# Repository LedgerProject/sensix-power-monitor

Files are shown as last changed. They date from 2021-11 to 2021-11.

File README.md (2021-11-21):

## SPD Enclosure based PowerMonitor - 2 DIN Modules - Single/Three Phase

## Table of contents

* [Built with](#built-with)
* [Software used](#dependencies)
* [Directory structure](#directory-structure)
* [Flash instructions](#flash-instructions)
* [Running tests](#running-tests)
* [Hardware Design](#hardware-design)

## Built with 

* [ESP-IDF](https://www.espressif.com/en/products/sdks/esp-idf)

## Software used 

* [ESP-IDF Toolchain](https://www.espressif.com/en/products/sdks/esp-idf)
* [CMake](https://cmake.org/download/)
* [Arduino ADE9153a](https://github.com/analogdevicesinc/arduino/tree/master/Arduino%20Uno%20R3/libraries/ADE9153A)
* [minfft](https://github.com/aimukhin/minfft)
* [fmtlib](https://github.com/fmtlib/fmt)
* [Microsoft GSL](https://github.com/microsoft/GSL)

## Directory structure 

* `3rdparty`: Third party code and dependencies
* `cmake`: Additional CMake scripts used to configure and build the project
* `data`: Resources embedded in the final binary
* `hardware_design`: Hardware design files
* `main`: ESP IDF component
* `src`: Source code
* `src/include`: Header files
* `test`: Unit tests (meant to be run on PC)

## Flash instructions 

After setting up the ESP IDF build environment and making sure the tools are available in your PATH, run:

```
idf.py build # Build the source code
idf.py -p <port> flash
idf.py -p <port> monitor
```

## Running tests 

Make sure you have CMake and CTest available in your PATH and a C and C++ compiler available.

Run:

```
mkdir build && cd build
cmake .. && cmake --build .
ctest
```

## Hardware Design 

Design files for PowerMonitor hardware for development:

* SPD_PowerMonitor-AFE - board containing the analog frontend and isolation barrier
* SPD_PowerMonitor-Controller - board containing the ESP32 MCU with RS485 and USB for software debugging

Characteristics:

* Designed to fit into a 2 DIN Module SPD base enclosure
* Instead of Ethernet and 24V AC power the controller has a USB transciever chip to ease development
* Powered by USB 5V DC
* Breakout headers for internal SPI bus in order to experiment with external RAM
* Breakout headers for I2C bus to add ST NFC module for configuration loading
* Shunt mounted directly on the SPD spade plugs

**Notes**

From software side this is the final design, any changes to hardware should be transparent to software. On hardware
side, because of chip shortages and especially the low availability of the isolated power supply for the AFE, this
design will have to be modified to use other ICs that are available. Analog FE will not change.

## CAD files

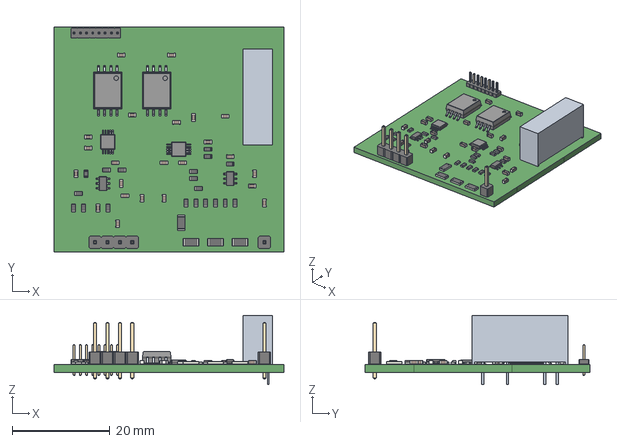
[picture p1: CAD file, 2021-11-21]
hardware_design/PowerMonitor-AFE/PowerMonitor-AFE/PowerMonitor-AFE.step
47.0 x 46.0 x 14.2 mm

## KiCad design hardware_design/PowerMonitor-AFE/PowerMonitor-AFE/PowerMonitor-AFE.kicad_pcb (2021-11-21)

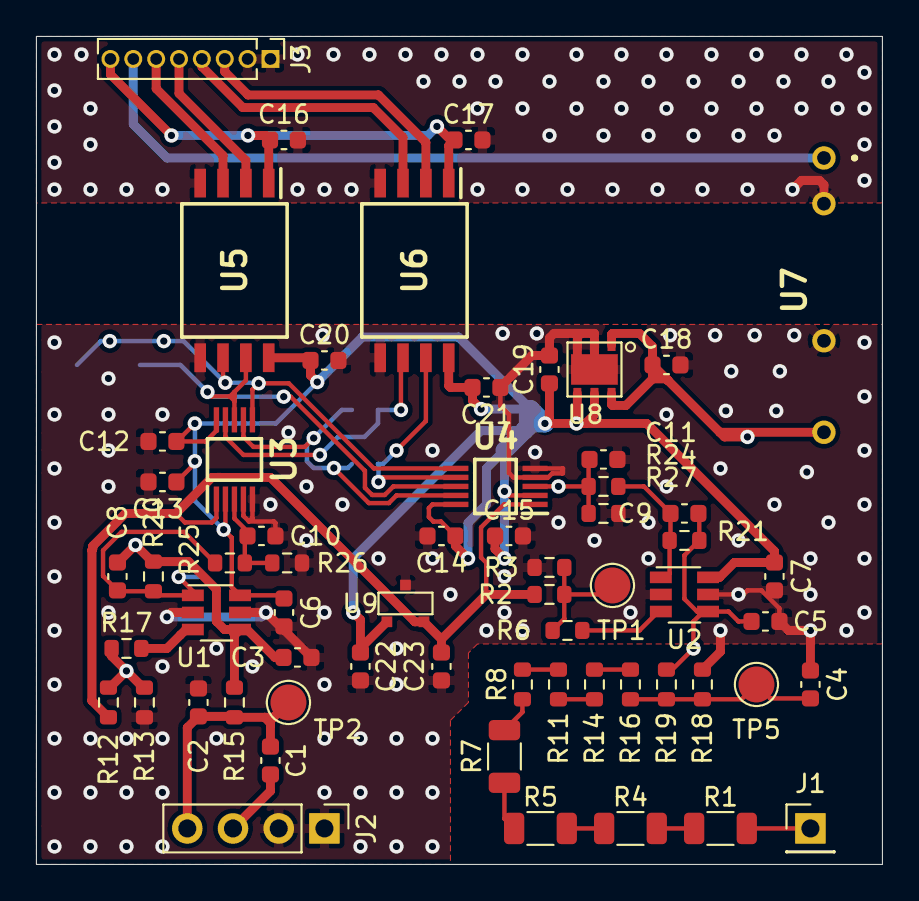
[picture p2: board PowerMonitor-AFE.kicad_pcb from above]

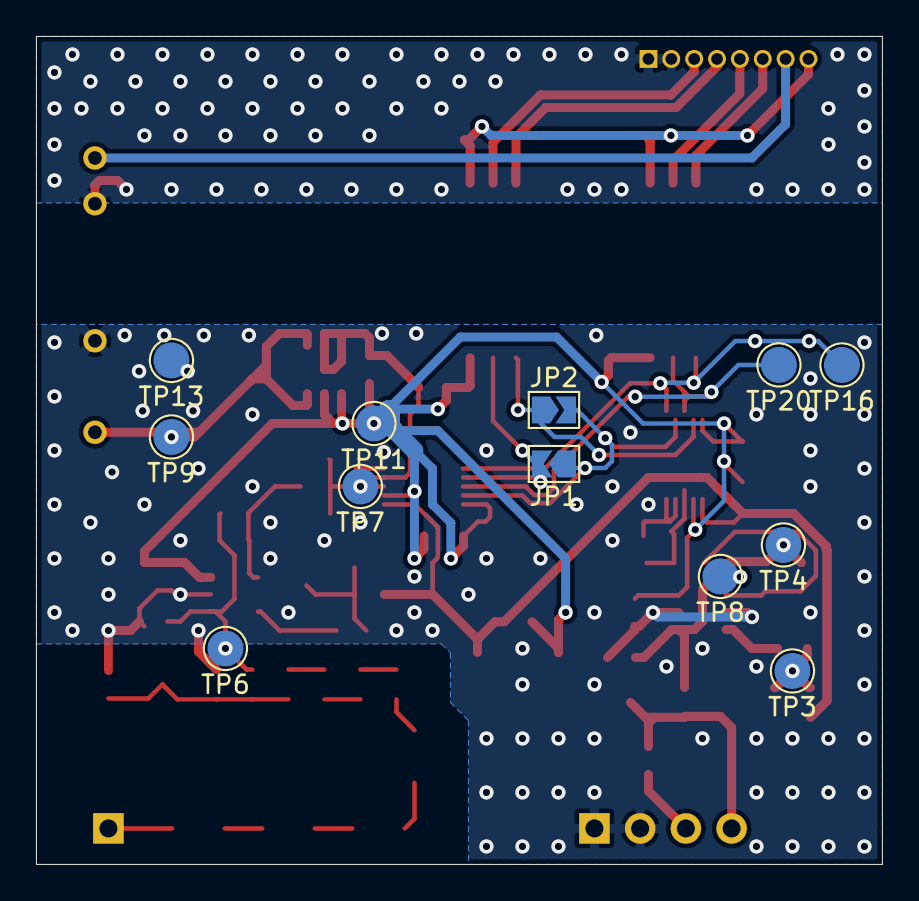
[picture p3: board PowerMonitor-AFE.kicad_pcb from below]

Board: 2 copper layers, 47.0 x 46.0 mm, 73 parts (12 on the bottom side), 37 nets.

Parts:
C1, C3, C5, C8, C9, C10, C11: DNP; C_0603_1608Metric
C2, C4: 1n; C_0603_1608Metric
C6, C7, C12, C13, C14, C15, C16, C17, C20, C21, C22: 0.1u; C_0603_1608Metric
C18, C19, C23: 1u; C_0603_1608Metric
J1: Conn_01x01; PinHeader_1x01_P2.54mm_Vertical
J2: Conn_01x04; PinHeader_1x04_P2.54mm_Vertical
J3: Conn_01x08; PinHeader_1x08_P1.27mm_Vertical
JP1, JP2: SolderJumper_2_Open; SolderJumper-2_P1.3mm_Open_TrianglePad1.0x1.5mm
R1, R4, R5, R7: 249k; R_1206_3216Metric
R2, R8, R11, R12, R14, R16, R24, R25, R26, R27: 1k; R_0603_1608Metric
R3, R13: 100; R_0603_1608Metric
R6, R17: 0R; R_0603_1608Metric
R15: 100K; R_0603_1608Metric
R18: 330; R_0603_1608Metric
R19: 100k; R_0603_1608Metric
R20, R21: 1M; R_0603_1608Metric
TP1, TP2, TP3, TP4, TP5, TP6, TP7, TP8, TP9, TP11, TP13, TP16, TP20: TestPoint; TestPoint_Pad_D2.0mm
U1, U2: ADA4098-1; TSOT-23-6
U3, U4: ADS8866; SOP50P490X110-10N
U5: MAX22245; SOIC127P1031X265-8N
U6: MAX22246; SOIC127P1031X265-8N
U7: TEA1-0505HI; TEA10505HI
U8: NCP691MN33T2G; DFN6 3x3 0.95
U9: ADR380ARTZ-REEL7; SOT-23

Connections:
+3.3VP: C6.2, C7.2, C12.2, C13.1, C14.2, C15.1, C19.1, C20.1, C21.1, C22.1, TP11.1, U1.6, U2.6, U3.2, U3.10, U4.2, U4.10, U5.8, U6.8, U8.4, U8.5, U9.1
+3V3: C16.1, C17.1, J3.8, U5.1, U6.1
+5V: J3.7, U7.1
+5VP: C18.1, TP9.1, U7.7, U8.1, U8.6
CONVST: TP16.1, U3.6, U4.6, U5.6
CONV_START: J3.6, U5.3
DIN_EXT: JP2.1, U3.9, U6.6
DOUT_A: JP1.1, JP2.2, U3.7, U4.9
DOUT_EXT: JP1.2, U4.7, U6.7
GND1: C16.2, C17.2, J3.1, J3.2, U5.4, U6.4, U7.2
GND2: C2.1, C3.1, C4.1, C5.1, C6.1, C7.1, C10.1, C11.1, C12.1, C13.2, C14.1, C15.2, C18.2, C19.2, C20.2, C21.2, C22.2, C23.2, J2.1, J2.2, R3.1, R13.1, R18.2, R26.2, R27.2, TP13.1, U1.2, U1.5, U2.2, U2.5, U3.4, U3.5, U4.4, U4.5, U5.5, U6.5, U7.5, U8.2, U8.3, U8.EP, U9.3
unnamed: C1.1, C2.2, J2.4, R15.1, TP2.1
unnamed: C1.2, J2.3
unnamed: C3.2, C8.2, R15.2, R20.2, TP4.1, U1.4
unnamed: C4.2, R16.2, R18.1, R19.1, TP5.1
unnamed: C5.2, C9.2, R19.2, R21.2, TP6.1, U2.4
unnamed: C8.1, R20.1, R25.1, TP8.1, U1.1
unnamed: C9.1, R21.1, R24.1, U2.1
unnamed: C10.2, R25.2, R26.1, U3.3
unnamed: C11.2, R24.2, R27.1, TP7.1, U4.3
unnamed: J1.1, R1.1
unnamed: R1.2, R4.1
unnamed: R2.2, R3.2, R6.1, TP1.1
unnamed: R4.2, R5.1
unnamed: R5.2, R7.1
unnamed: R6.2, U2.3
unnamed: R7.2, R8.1
unnamed: R8.2, R11.1
unnamed: R11.2, R14.1
unnamed: R12.2, R13.2, R17.1, TP3.1
unnamed: R14.2, R16.1
unnamed: R17.2, U1.3
SCLK: TP20.1, U3.8, U4.8, U5.7
SPI_0_CLK: J3.5, U5.2
SPI_0_MISO: J3.3, U6.2
SPI_0_MOSI: J3.4, U6.3
VREF: C23.1, R2.1, R12.1, U3.1, U4.1, U9.2

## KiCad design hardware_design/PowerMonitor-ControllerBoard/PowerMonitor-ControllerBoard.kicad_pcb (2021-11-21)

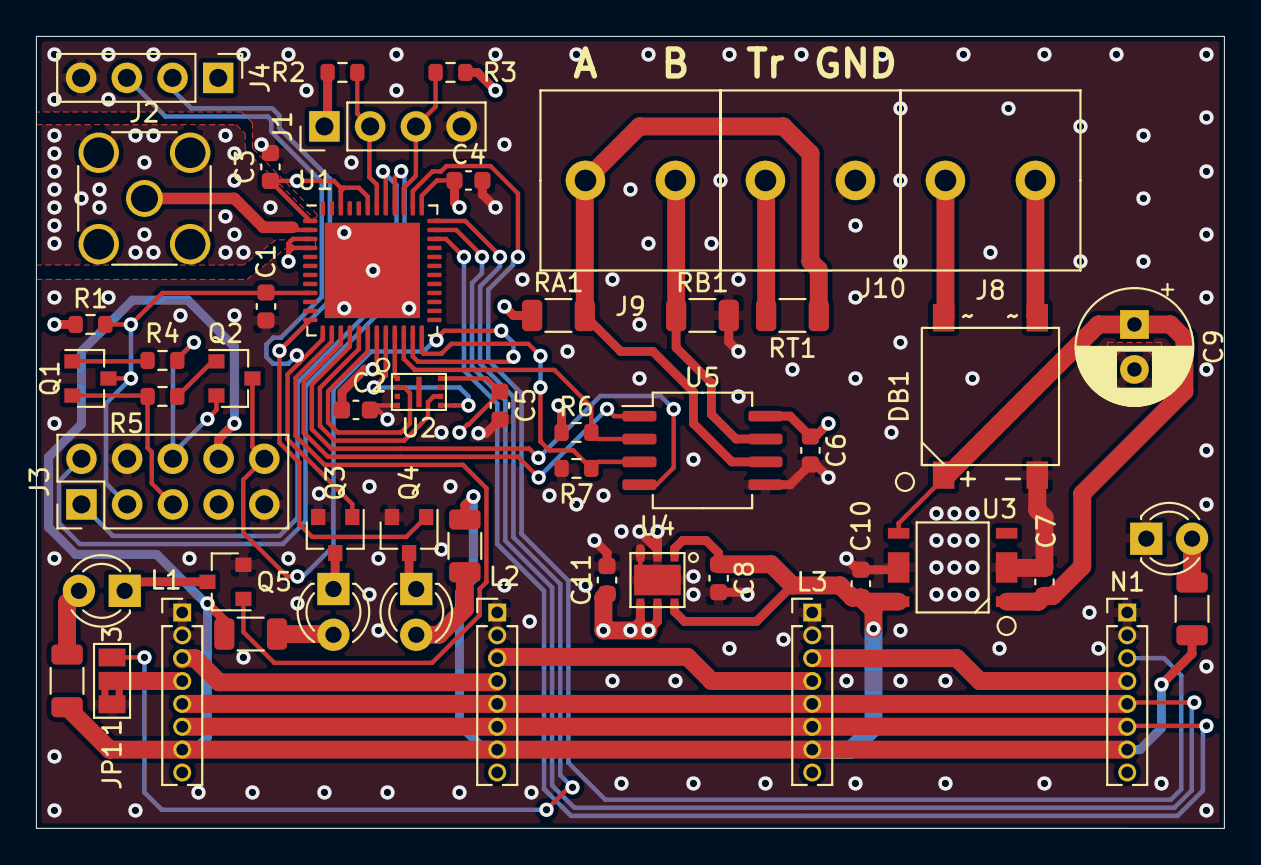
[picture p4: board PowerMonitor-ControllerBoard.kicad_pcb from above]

Board: 4 copper layers, 66.0 x 44.0 mm, 52 parts (0 on the bottom side), 46 nets.

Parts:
C1, C2, C3, C4, C5, C6, C7, C10: 0.1u; C_0603_1608Metric
C8, C11: 1u; C_0603_1608Metric
C9: 4700u; CP_Radial_D6.3mm_P2.50mm
DB1: DF01S-T
J1: CON_I2C; PinHeader_1x04_P2.54mm_Vertical
J2: Conn_Coaxial; SMA_Wurth_60312002114503_Vertical
J3: Conn_02x05_Counter_Clockwise; PinHeader_2x05_P2.54mm_Vertical
J4: Conn_01x04; PinHeader_1x04_P2.54mm_Vertical
J8, J9, J10: Conn_01x02; 1792863
JP1: DATA_OUT_SEL; SolderJumper-3_P1.3mm_Bridged2Bar12_Pad1.0x1.5mm_NumberLabe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
L1, L2, L3: Conn_01x08; PinHeader_1x08_P1.27mm_Vertical
LED_ACT1: LED; LED_D3.0mm
LED_ALERT_1, LED_ALERT_2: LED; LED_D3.0mm
LED_PWR1: LED; LED_D3.0mm
N1: Conn_01x08; PinHeader_1x08_P1.27mm_Vertical
Q1, Q2, Q3, Q4, Q5: Q_NPN_BEC; SOT-23
R1, R6, R7: 10k; R_0603_1608Metric
R2, R3: 2k2; R_0603_1608Metric
R4, R5: 1k; R_0603_1608Metric
RA1: 1k; R_1206_3216Metric
RB1: 1k; R_1206_3216Metric
RT1: 120; R_1206_3216Metric
R_LED_ACT1: TBD; R_1206_3216Metric
R_LED_ALERT_1, R_LED_ALERT_2: TBD; R_1206_3216Metric
R_LED_PWR1: TBD; R_1206_3216Metric
U1: ESP32-PICO-D4; QFN-48-1EP_7x7mm_P0.5mm_EP5.3x5.3mm
U2: APS1604M-3SQR-ZR; USON-8L 3x2 ZR
U3: R1518S501B-E2-FE; HSOP-6J
U4: NCP691MN33T2G; DFN6 3x3 0.95
U5: MAX3485; SO-8_5.3x6.2mm_P1.27mm

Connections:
+3V3: C2.1, C3.1, C4.1, C5.1, C6.1, C11.1, J1.1, J3.7, J4.1, L1.8, L2.8, L3.8, N1.8, R1.1, R2.1, R3.1, R6.1, RA1.1, U1.1, U1.3, U1.4, U1.19, U1.37, U1.43, U1.46, U2.8, U4.4, U4.5, U5.8
+5V: C8.1, C10.1, J3.8, L1.7, L2.7, L3.7, N1.7, R_LED_ACT1.1, R_LED_ALERT_1.1, R_LED_ALERT_2.1, R_LED_PWR1.1, U3.6, U4.1, U4.6
ACT_LED: Q5.1, U1.14
ALERT_1: J4.2, Q4.1, U1.12
ALERT_2: J4.3, Q3.1, U1.13
BOOT_MODE: J3.10, Q2.3, U1.23
CONV_START: L1.6, L2.6, L3.6, N1.6, U1.34
DE: R7.1, U1.24, U5.3
DTR: J3.6, Q2.2, R4.1
EN: C1.1, J3.3, Q1.3, R1.2, U1.9
GND: C1.2, C2.2, C3.2, C4.2, C5.2, C6.2, C7.2, C8.2, C9.2, C10.2, C11.2, DB1.3, J1.4, J2.2, J3.4, J3.9, J4.4, J10.2, JP1.1, L1.1, L1.2, L2.1, L2.2, L3.1, L3.2, LED_PWR1.1, N1.1, N1.2, Q3.2, Q4.2, Q5.2, R7.2, RB1.2, U1.49, U2.4, U3.2, U3.5, U4.2, U4.3, U4.EP, U5.5
LNA: J2.1, U1.2
unnamed: DB1.2, J8.2
unnamed: DB1.4, J8.1
unnamed: JP1.2, L1.4
unnamed: L1.3, L2.4
unnamed: L2.3, L3.4
unnamed: L3.3, N1.4
unnamed: LED_ACT1.1, Q5.3
unnamed: LED_ACT1.2, R_LED_ACT1.2
unnamed: LED_ALERT_1.1, Q4.3
unnamed: LED_ALERT_1.2, R_LED_ALERT_1.2
unnamed: LED_ALERT_2.1, Q3.3
unnamed: LED_ALERT_2.2, R_LED_ALERT_2.2
unnamed: LED_PWR1.2, R_LED_PWR1.2
unnamed: Q1.1, R4.2
unnamed: Q2.1, R5.2
RE: R6.2, U1.22, U5.2
RS485_A: J9.1, RA1.2, RT1.1, U5.6
RS485_B: J9.2, RB1.1, U5.7
RS485_TR: J10.1, RT1.2
RTS: J3.5, Q1.2, R5.1
RXD0: J3.2, U1.40
RXD1: U1.15, U5.1
SCL: J1.3, R3.2, U1.39
SDA: J1.2, R2.2, U1.42
SPI_0_CLK: L1.5, L2.5, L3.5, N1.5, U1.35
SPI_0_MISO: N1.3, U1.38
SPI_0_MOSI: JP1.3, U1.36
SPI_1_CLK: U1.17, U2.6
SPI_1_CS: U1.21, U2.1
SPI_1_MISO: U1.18, U2.2
SPI_1_MOSI: U1.20, U2.5
TXD0: J3.1, U1.41
TXD1: U1.16, U5.4
VDC: C7.1, C9.1, DB1.1, U3.1, U3.4

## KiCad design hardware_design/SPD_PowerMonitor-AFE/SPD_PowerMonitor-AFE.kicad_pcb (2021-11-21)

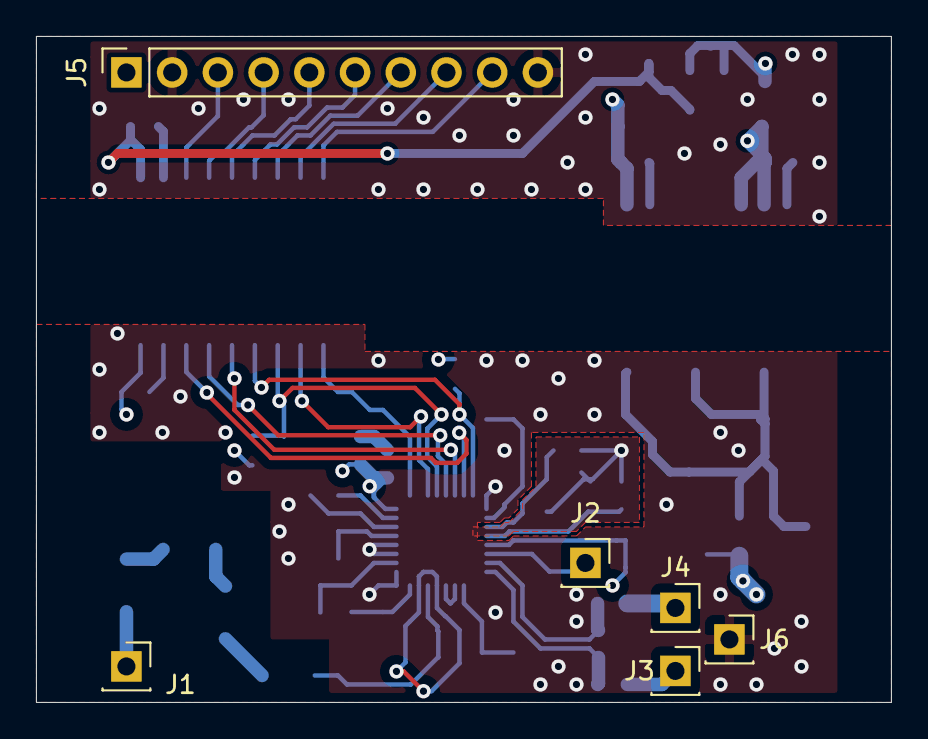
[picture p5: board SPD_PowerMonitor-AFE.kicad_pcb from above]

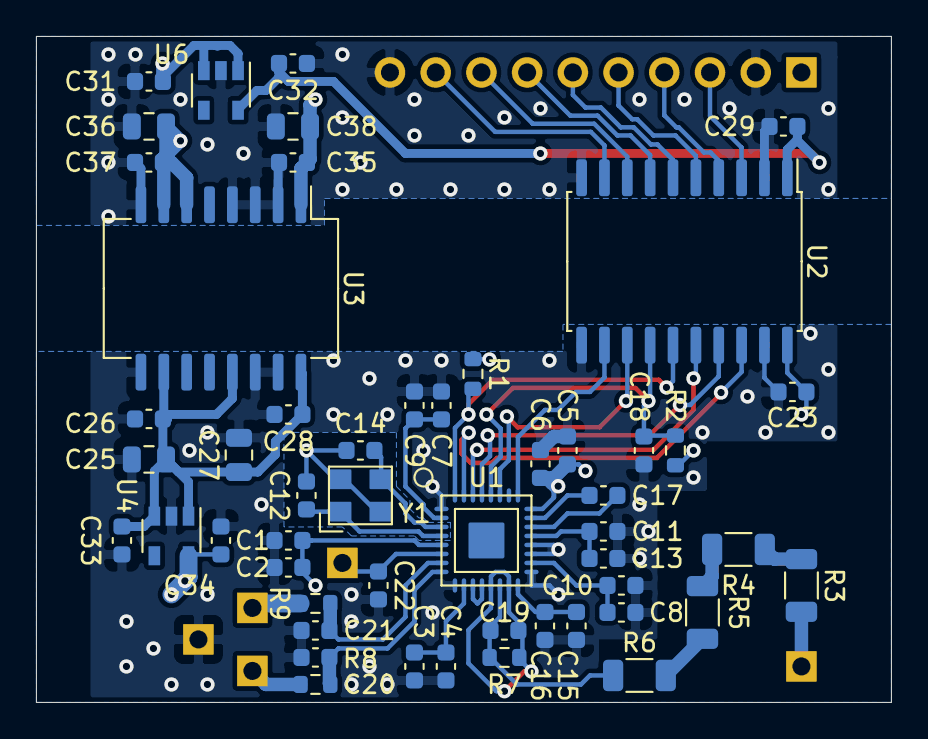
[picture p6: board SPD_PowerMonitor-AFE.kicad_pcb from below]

Board: 4 copper layers, 47.5 x 37.0 mm, 57 parts (51 on the bottom side), 41 nets.

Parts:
C1, C3, C5, C7, C8, C15: 4.7uF; C_0603_1608Metric
C2, C4, C6, C9, C10, C13, C16, C20, C21, C22, C23, C26, C28, C29, C35, C37: 0.1uF; C_0603_1608Metric
C11, C17: 0.47uF; C_0603_1608Metric
C12, C14: 12pF; C_0603_1608Metric
C18: 1uF; C_0603_1608Metric
C19: 15nF; C_0603_1608Metric
C25, C27, C36, C38: 10uF; C_0805_2012Metric
C31, C32, C33, C34: C; C_0603_1608Metric
J1, J2, J3, J4, J6: Conn_01x01; PinSocket_1x01_P2.54mm_Vertical
J5: Conn_01x10; PinSocket_1x10_P2.54mm_Vertical
R1, R2: 10k; R_0603_1608Metric
R3, R4, R5, R6: 250k; R_1206_3216Metric
R7: 1k; R_0603_1608Metric
R8, R9: 150k; R_0603_1608Metric
U1: ADE9153A; LFCSP_5_5_0.75_32
U2: ADuM4152BRIZ; SOIC-20W_7.5x12.8mm_P1.27mm
U3: ADuM6000ARIZ; SOIC-16W_7.5x12.8mm_P1.27mm
U4, U6: AP2112K-3.3; SOT-23-5
Y1: 12.288MHz 12pF 20ppm; ECX-33Q

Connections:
AVDDOUT: C15.1, C16.1, U1.16
CF2_LIVE: U1.25, U2.12
CF_2: J5.9, U2.9
CLKIN: C12.1, U1.4, Y1.1
CLKOUT: C14.1, U1.3, Y1.3
DVDDOUT: C7.1, C9.1, U1.2
GND: C1.2, C2.2, C3.2, C4.2, C5.2, C6.2, C7.2, C8.2, C9.2, C10.2, C11.2, C12.2, C13.2, C14.2, C15.2, C16.2, C18.2, C20.2, C21.1, C22.2, C23.2, C25.2, C26.2, C27.2, C28.2, C33.2, C34.2, J6.1, U1.1, U1.9, U1.17, U1.19, U1.20, U2.11, U2.19, U3.9, U3.14, U3.15, U4.2, Y1.2, Y1.4
GNDD: C29.2, C31.2, C32.2, C35.2, C36.2, C37.2, C38.2, J5.2, J5.10, U2.2, U2.10, U3.2, U3.3, U3.4, U3.8, U6.2
IAMS: C22.1, J2.1, U1.6
IAN: C21.2, R9.2, U1.7
IAP: C20.1, R8.2, U1.8
IRQ: J5.8, U2.8
IRQ_LIVE: U1.27, U2.13
LIN: J3.1, R8.1
LOUT: J4.1, R9.1
MISO: J5.5, U2.5
MISO_LIVE: U1.30, U2.16
MOSI: J5.4, U2.4
MOSI_LIVE: U1.29, U2.17
MSH: C11.1, C13.1, U1.21
N: J1.1, R3.2
unnamed: C17.1, U1.23
unnamed: C17.2, U1.22
unnamed: R3.1, R4.2
unnamed: R4.1, R5.2
unnamed: R5.1, R6.2
unnamed: U1.11, U1.12
REFIN: C8.1, C10.1, U1.18
RESET: J5.7, U2.7
RESET_LIVE: C18.1, R2.2, U1.28, U2.14
SCLK: J5.3, U2.3
SCLK_LIVE: U1.31, U2.18
SS: J5.6, U2.6
SS_LIVE: R1.2, U1.32, U2.15
V3V3: C29.1, C32.1, U2.1, U6.5
V3V3_ISO: C1.1, C2.1, C5.1, C6.1, C23.1, C34.1, R1.1, R2.1, U1.5, U1.24, U2.20, U4.5
V5V: C31.1, C35.1, C36.1, C37.1, C38.1, J5.1, U3.1, U3.6, U3.7, U6.1, U6.3
V5V_ISO: C25.1, C26.1, C27.1, C28.1, C33.1, U3.10, U3.13, U3.16, U4.1, U4.3
VAN: C19.2, R7.1, U1.13, U1.15
VAP: C19.1, R6.1, R7.2, U1.14
VDDOUT2P5: C3.1, C4.1, U1.10

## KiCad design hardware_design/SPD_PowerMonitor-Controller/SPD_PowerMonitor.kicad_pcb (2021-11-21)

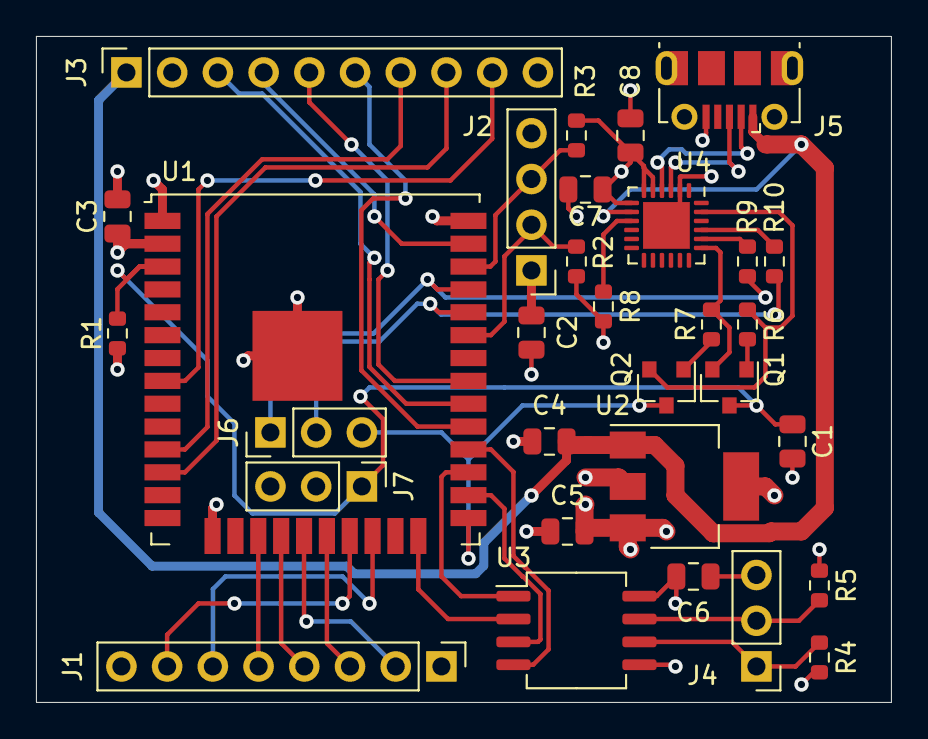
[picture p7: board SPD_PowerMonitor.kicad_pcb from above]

Board: 4 copper layers, 47.5 x 37.0 mm, 31 parts (0 on the bottom side), 37 nets.

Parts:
C1, C2, C3, C4, C5, C6, C7, C8: C; C_0805_2012Metric
J1: Conn_01x08; PinHeader_1x08_P2.54mm_Vertical
J2: Conn_01x04; PinHeader_1x04_P2.54mm_Vertical
J3: Conn_01x10; PinSocket_1x10_P2.54mm_Vertical
J4, J6, J7: Conn_01x03; PinHeader_1x03_P2.54mm_Vertical
J5: USB_B_Micro; USB_Micro-B_Molex-105017-0001
Q1, Q2: Q_NPN_BEC; SOT-23
R1, R2, R3, R4, R5, R6, R7, R8, R9, R10: R; R_0603_1608Metric
U1: ESP32-WROOM-32U
U2: TC1262-33; SOT-223-3_TabPin2
U3: MAX3485; SO-8_5.3x6.2mm_P1.27mm
U4: CP2102N-A01-GQFN24; QFN-24-1EP_4x4mm_P0.5mm_EP2.6x2.6mm

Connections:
+3V3: C2.1, C3.1, C5.1, C6.1, C7.1, C8.1, J1.8, J2.1, R1.1, R2.1, R3.1, R4.1, R8.1, U1.2, U2.3, U3.8, U4.5, U4.6, U4.7
+5V: C4.1, J3.1, J5.1, U2.1, U4.8
BOOT_MODE: J6.3, Q2.3, U1.25
CF2_ADE: J3.9, U1.8
DE: U1.26, U3.3
DTR: Q2.2, R6.2, U4.23
EN: C1.1, J7.1, Q1.3, R1.2, U1.3
GND: C1.2, C2.2, C3.2, C4.2, C5.2, C6.2, C7.2, C8.2, J1.1, J2.4, J3.2, J3.10, J4.3, J5.5, J7.2, J7.3, R5.2, U1.1, U1.15, U1.38, U1.39, U2.2, U3.5, U4.2, U4.25
IRQ_ADE: J3.8, U1.12
unnamed: J1.2, U1.19
unnamed: J1.3, U1.20
unnamed: J1.4, U1.18
unnamed: J1.5, U1.17
unnamed: J1.6, U1.22
unnamed: J1.7, U1.21
unnamed: J4.1, R4.2, U3.6
unnamed: J4.2, R5.1, U3.7
unnamed: J5.2, U4.4
unnamed: J5.3, U4.3
unnamed: Q1.1, R6.1
unnamed: Q2.1, R7.1
unnamed: R8.2, U4.9
unnamed: R9.2, U4.20
unnamed: R10.2, U4.21
RE: U1.24, U3.2
RESET_ADE: J3.7, U1.11
RTS: Q1.2, R7.2, U4.19
RXD0: J6.2, R10.1, U1.34
RXD2: U1.27, U3.1
SCL: J2.3, R3.2, U1.36
SDA: J2.2, R2.2, U1.33
SPI_CLK: J3.3, U1.30
SPI_CS_0: J3.6, U1.29
SPI_MISO: J3.5, U1.31
SPI_MOSI: J3.4, U1.37
TXD0: J6.1, R9.1, U1.35
TXD2: U1.28, U3.4

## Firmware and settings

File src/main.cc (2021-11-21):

#ifdef POWER_MONITOR_PLATFORM_XTENSA

#include "afe_reader.hh"
#include "common.hh"
#include "resources.h"

#include <elsen/arduino_compatibility.hh>
#include <elsen/logger.hh>
#include <elsen/mqtt_client.hh>
#include <elsen/wifi.hh>

#include <gsl/gsl>

#include <esp_event.h>
#include <esp_http_client.h>
#include <esp_task_wdt.h>
#include <esp_tls.h>
#include <esp_wifi.h>
#include <nvs_flash.h>

#include <string_view>

namespace
{
    constexpr auto PAYLOAD_TARGET_TOPIC =
        std::string_view{ "v1/GesIuWDVKLqsYYXG/devices/DEADBFEED0000000/0/bin" };

    constexpr auto DEFAULT_INTERVAL_MS = std::chrono::milliseconds{ 2 * 1000 }.count();

    constexpr auto BURST_MODE_TOPIC =
        std::string_view{ "v1/GesIuWDVKLqsYYXG/devices/DEADBFEED0000000/0/config" };
    constexpr auto BURST_MODE_INTERVAL_MS        = std::chrono::milliseconds{ 5 * 1000 }.count();
    constexpr auto BURST_MODE_MAX_ACTIVE_TIME_MS = std::chrono::milliseconds{ 20 * 1000 }.count();

    constexpr auto HTTP_POST_INTERVAL_MS = std::chrono::milliseconds{ 900 * 1000 }.count();

    inline void initialize_nvs()
    {
        auto ret = nvs_flash_init();
        if (ret == ESP_ERR_NVS_NO_FREE_PAGES || ret == ESP_ERR_NVS_NEW_VERSION_FOUND)
        {
            ESP_ERROR_CHECK(nvs_flash_erase());
            ret = nvs_flash_init();
        }
        ESP_ERROR_CHECK(ret);
    }

    inline void initialize_tcp_ip_stack()
    {
        ESP_ERROR_CHECK(esp_netif_init());
    }

    inline void create_main_event_loop()
    {
        ESP_ERROR_CHECK(esp_event_loop_create_default());
    }

    inline void initialize_wifi()
    {
        esp_netif_create_default_wifi_sta();
        const wifi_init_config_t cfg = WIFI_INIT_CONFIG_DEFAULT();
        ESP_ERROR_CHECK(esp_wifi_init(&cfg));
    }

    inline void send_cumulated_energy(float value)
    {
        esp_http_client_config_t config{};
        config.url                         = "https://apiroom.net/api/lucianovici/power_monitor";
        config.cert_pem                    = reinterpret_cast<const char *>(resource_ISRG_Root_X1);
        config.method                      = esp_http_client_method_t::HTTP_METHOD_POST;
        config.skip_cert_common_name_check = true;
        auto client                        = esp_http_client_init(&config);

        esp_http_client_set_header(client, "Accept", "application/json");
        esp_http_client_set_header(client, "Content-Type", "application/json");

        auto payload =
            fmt::format("{{ \"data\": {{ \"kwh\": {} }}, \"keys\": {{}} }}", value / 1'000.F);
        esp_http_client_set_post_field(client,
            payload.c_str(),
            static_cast<std::int32_t>(payload.size()));

        std::printf("Sending: %s\n", payload.c_str());

        ESP_ERROR_CHECK(esp_http_client_perform(client));

        ESP_ERROR_CHECK(esp_http_client_cleanup(client));
    }
} // namespace

int main(int argc, char *argv[])
{
    ELSEN_UNUSED(argc);
    ELSEN_UNUSED(argv);

    initialize_nvs();

    esp_err_t esp_ret = ESP_FAIL;
    esp_ret           = esp_tls_set_global_ca_store(resource_ISRG_Root_X1,
                  static_cast<std::uint32_t>(resource_ISRG_Root_X1_size));
    if (esp_ret != ESP_OK)
    {
        ELSEN_LOG_ERROR("Error in setting the global ca store: [{:x}] ({}),could not complete the "
                        "https_request using global_ca_store",
            esp_ret,
            esp_err_to_name(esp_ret));
        vTaskDelay(5 * 1000 / portTICK_PERIOD_MS);
        std::exit(EXIT_FAILURE);
    }

    initialize_tcp_ip_stack();
    create_main_event_loop();
    initialize_wifi();

    elsen::signal::platform_init_queued_signal_handler();

    static auto wifi        = elsen::WiFi{};
    static auto mqtt_client = elsen::MQTTClient{};

    static auto burst_mode_active{ false };
    static auto burst_mode_active_since = std::chrono::system_clock::now();
    static auto last_sent           = std::chrono::system_clock::now() - std::chrono::hours{ 1 };
    static auto last_http_post_sent = std::chrono::system_clock::now() - std::chrono::hours{ 1 };

    static auto afe_reader = new AfeReader{};
    afe_reader->readings_ready.connect(
        [](std::vector<std::uint8_t> &&readings_serialized) noexcept {
            if (mqtt_client.is_connected())
            {
                const auto time_since_last_sent_ms =
                    std::chrono::duration_cast<std::chrono::milliseconds>(
                        std::chrono::system_clock::now() - last_sent)
                        .count();

                if ((burst_mode_active && time_since_last_sent_ms >= BURST_MODE_INTERVAL_MS) ||
                    (time_since_last_sent_ms >= DEFAULT_INTERVAL_MS))
                {
                    readings_serialized.insert(readings_serialized.cbegin(), 0);
                    readings_serialized.insert(readings_serialized.cbegin(), 0);
                    mqtt_client.publish_message(PAYLOAD_TARGET_TOPIC,
                        readings_serialized.data(),
                        readings_serialized.size());

                    last_sent = std::chrono::system_clock::now();

                    const auto time_since_burst_mode_active =
                        std::chrono::duration_cast<std::chrono::milliseconds>(
                            std::chrono::system_clock::now() - burst_mode_active_since)
                            .count();
                    if (time_since_burst_mode_active > BURST_MODE_MAX_ACTIVE_TIME_MS)
                    {
                        burst_mode_active = false;
                    }
                }

                const auto time_since_http_post =
                    std::chrono::duration_cast<std::chrono::milliseconds>(
                        std::chrono::system_clock::now() - last_http_post_sent)
                        .count();
                if (time_since_http_post >= HTTP_POST_INTERVAL_MS)
                {
                    send_cumulated_energy(afe_reader->cumulated_active_energy());
                    last_http_post_sent = std::chrono::system_clock::now();
                }
            }
            else
            {
                ELSEN_LOG_WARN("No MQTT connection available. Cannot send readings.");
            }
        },
        elsen::signal::ConnectionType::Queued);

    wifi.connected.connect([](std::uint32_t ip_address) {
        ELSEN_LOG_INFO("Connected to access point with SSID: \"{}\"", WIFI_SSID);

        const auto esp_ip_addr = esp_ip4_addr_t{ ip_address };
        ELSEN_LOG_INFO("Ip address: {}.{}.{}.{}", IP2STR(&esp_ip_addr));

        ELSEN_LOG_INFO("Connecting to MQTT broker...");
        mqtt_client.set_broker_url(MQTT_BROKER_URL, MQTT_TLS_PORT);
        mqtt_client.set_username(MQTT_USERNAME);
        mqtt_client.set_password(MQTT_PASSWORD);
        mqtt_client.connect();
    });

    mqtt_client.connected.connect(
        [](AfeReader *afe) {
            std::srand(static_cast<std::uint32_t>(std::chrono::duration_cast<std::chrono::seconds>(
                std::chrono::system_clock::now().time_since_epoch())
                                                      .count()));

            ELSEN_LOG_INFO("MQTT: Connected to {}...", MQTT_BROKER_URL);
            afe->start_reading();
            mqtt_client.subscribe(BURST_MODE_TOPIC);
        },
        *afe_reader);

    mqtt_client.subscribed.connect([](elsen::MQTTClient::MessageID) noexcept {
        ELSEN_LOG_INFO("MQTT subscribed to topic");
    });

    mqtt_client.received.connect([](std::string_view topic, auto data) {
        ELSEN_UNUSED(data);
        if (topic == BURST_MODE_TOPIC)
        {
            ELSEN_LOG_INFO("Toggling burst mode {}...", (burst_mode_active ? "OFF" : "ON"));
            burst_mode_active_since = std::chrono::system_clock::now();
            burst_mode_active       = !burst_mode_active;
        }
    });

    wifi.connection_failed.connect([]() {
        ELSEN_LOG_ERROR("Failed to connect to Access Point \"{}\"", WIFI_SSID);
        vTaskDelay((5 * 1000) / portTICK_PERIOD_MS);
        std::exit(EXIT_FAILURE);
    });

    wifi.disconnected.connect([]() {
        ELSEN_LOG_INFO("WiFi disconnected. Trying to reconnect...");
        mqtt_client.disconnect();
        wifi.connect();
    });

    ELSEN_LOG_INFO("Connecting to WiFi access point...");
    wifi.set_ssid(WIFI_SSID);
    wifi.set_password(WIFI_PASSWORD);
    wifi.set_authentication(elsen::WiFi::AuthenticationMode::WPA2_PSK);
    wifi.connect();

    for (;;)
    {
        vTaskDelay(portMAX_DELAY);
    }
}

#endif

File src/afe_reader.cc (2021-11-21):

#ifdef POWER_MONITOR_PLATFORM_XTENSA

#include "afe_reader.hh"
#include "math.hh"

#include <elsen/arduino_compatibility.hh>
#include <elsen/global.hh>
#include <elsen/logger.hh>
#include <elsen/utilities.hh>

#include <gsl/gsl>
#include <hedley/hedley.h>
#include <minfft.h>

#include <driver/spi_master.h>
#include <esp_pthread.h>

#include <pthread.h>

#include <bitset>
#include <cstdint>
#include <numeric>

#define PTHREAD_CHECK(result, message)                                    \
    do                                                                    \
    {                                                                     \
        if (result != 0)                                                  \
        {                                                                 \
            ELSEN_LOG_ERROR(message ". pthread API returned {}", result); \
            for (;;)                                                      \
                ;                                                         \
        }                                                                 \
    } while (false)

namespace
{
    constexpr std::uint32_t SPI_SPEED{ 2000000 };
    constexpr std::uint8_t  CS_PIN{ 5 };

    inline void init_timer(void (*callback)(void *),
        void               *callback_argument,
        esp_timer_handle_t &timer) noexcept
    {
        auto timer_config                  = esp_timer_create_args_t{};
        timer_config.callback              = callback;
        timer_config.arg                   = callback_argument;
        timer_config.dispatch_method       = ESP_TIMER_ISR;
        timer_config.name                  = "afe_reader";
        timer_config.skip_unhandled_events = true;

        esp_timer_create(&timer_config, &timer);
    }

    inline void set_up_pthread_config() noexcept
    {
        auto esp_pthread_cfg        = esp_pthread_get_default_config();
        esp_pthread_cfg.pin_to_core = 1;
        esp_pthread_cfg.prio        = 1;
        esp_pthread_cfg.stack_size  = 256;
        esp_pthread_cfg.thread_name = "afe_reader";
        ESP_ERROR_CHECK(esp_pthread_set_cfg(&esp_pthread_cfg));
    }

    inline void reset_pthread_config() noexcept
    {
        auto esp_pthread_cfg = esp_pthread_get_default_config();
        ESP_ERROR_CHECK(esp_pthread_set_cfg(&esp_pthread_cfg));
    }
} // namespace

AfeReader::AfeReader() noexcept
{
    using namespace elsen::arduino;
    using namespace elsen::signal;

    auto *address       = heap_caps_malloc(sizeof(DataBuffer), MALLOC_CAP_SPIRAM);
    current_samples_p1_ = new (address) DataBuffer{};

    address             = heap_caps_malloc(sizeof(DataBuffer), MALLOC_CAP_SPIRAM);
    voltage_samples_p1_ = new (address) DataBuffer{};

    address             = heap_caps_malloc(sizeof(DataBuffer), MALLOC_CAP_SPIRAM);
    current_samples_p2_ = new (address) DataBuffer{};

    address             = heap_caps_malloc(sizeof(DataBuffer), MALLOC_CAP_SPIRAM);
    voltage_samples_p2_ = new (address) DataBuffer{};

    address             = heap_caps_malloc(sizeof(DataBuffer), MALLOC_CAP_SPIRAM);
    current_samples_p3_ = new (address) DataBuffer{};

    address             = heap_caps_malloc(sizeof(DataBuffer), MALLOC_CAP_SPIRAM);
    voltage_samples_p3_ = new (address) DataBuffer{};

    address            = heap_caps_malloc(sizeof(DataBuffer), MALLOC_CAP_SPIRAM);
    current_samples_n_ = new (address) DataBuffer{};

    pinMode(CS_PIN, OUTPUT);
    digitalWrite(CS_PIN, LOW);

    ELSEN_LOG_INFO("Initializing AFE...");

    current_samples_n_->buffer_full.connect<&AfeReader::update_readings>(*this,
        ConnectionType::Queued);

    const auto spi_device_id =
        spi_.register_device({ SPI_SPEED, SpiMasterBus::DataMode::SPI_MODE0 });
    spi_device_ = &spi_.device(spi_device_id);
}

void AfeReader::start_reading() noexcept
{
    ELSEN_LOG_INFO("Preparing to read data from AFE...");

    set_up_pthread_config();

    auto thread_id = pthread_t{};
    auto result    = pthread_create(&thread_id, nullptr, &AfeReader::read_instance_values, this);
    PTHREAD_CHECK(result, "Failed to create instant value reader thread");

    result = pthread_detach(thread_id);
    PTHREAD_CHECK(result, "Failed to detach instant value reader thread");

    init_timer(&AfeReader::timer_callback, this, read_timer_);
    esp_timer_start_periodic(read_timer_, 244);

    ELSEN_LOG_INFO("Timer and task started, readings are ongoing...");

    reset_pthread_config();
}

void AfeReader::update_readings() noexcept
{
    using Span = gsl::span<float, DataBuffer::SIZE>;

    const auto start = std::chrono::system_clock::now();

    const auto samples_per_cycle_vp1 = helpers::samples_per_cycle(
        gsl::span<float>{ voltage_samples_p1_->inactive_buffer().data(), DataBuffer::SIZE });
    const auto samples_per_cycle_vp2 = helpers::samples_per_cycle(
        gsl::span<float>{ voltage_samples_p2_->inactive_buffer().data(), DataBuffer::SIZE });
    const auto samples_per_cycle_vp3 = helpers::samples_per_cycle(
        gsl::span<float>{ voltage_samples_p3_->inactive_buffer().data(), DataBuffer::SIZE });

    const auto samples_per_cycle_cp1 = helpers::samples_per_cycle(
        gsl::span<float>{ current_samples_p1_->inactive_buffer().data(), DataBuffer::SIZE });
    const auto samples_per_cycle_cp2 = helpers::samples_per_cycle(
        gsl::span<float>{ current_samples_p2_->inactive_buffer().data(), DataBuffer::SIZE });
    const auto samples_per_cycle_cp3 = helpers::samples_per_cycle(
        gsl::span<float>{ current_samples_p3_->inactive_buffer().data(), DataBuffer::SIZE });

    auto minfft_context =
        std::unique_ptr<minfft_aux, decltype(&minfft_free_aux)>{ minfft_mkaux_dft_1d(
                                                                     DataBuffer::SIZE),
            &minfft_free_aux };
    if (minfft_context == nullptr)
    {
        fprintf(stderr, "PowerMonitor: Failed to allocate FFT structure\n");
        return;
    }

    /** VOLTAGE **/
    {
        auto *sample_buffer_p1 = voltage_samples_p1_->inactive_buffer().data();
        auto *sample_buffer_p2 = voltage_samples_p2_->inactive_buffer().data();
        auto *sample_buffer_p3 = voltage_samples_p3_->inactive_buffer().data();

        auto input = std::vector<minfft_cmpl>(DataBuffer::SIZE);
        {
            for (std::size_t i = 0; i < DataBuffer::SIZE; ++i)
            {
                input[i][0] = sample_buffer_p1[i];
                input[i][1] = .0f;
            }

            auto *output = input.data();
            minfft_dft(input.data(), output, minfft_context.get());

            readings_.set_voltage_hd_phase_1(output, DataBuffer::SIZE);
            readings_.set_rms_voltage_phase_1(rms(Span{ sample_buffer_p1, DataBuffer::SIZE }));
        }

        {
            for (std::size_t i = 0; i < DataBuffer::SIZE; ++i)
            {
                input[i][0] = sample_buffer_p2[i];
                input[i][1] = .0f;
            }
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
